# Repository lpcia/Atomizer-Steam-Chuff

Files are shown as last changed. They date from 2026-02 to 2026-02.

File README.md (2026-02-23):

# Atomizer-Steam-Chuff
Small circuit Using a 5V Humidifier/Atomizer Module to simulate Locomotive Steam Chuff using Track Power

# Steam Chuff Controller Build Guide  
   (Yes, it was created by AI and it kind of sucks, but it's pretty complete until I can edit it.)

## Complete 555-Based Ultrasonic Atomizer Controller for Model Railroads

---

## Table of Contents

1. [Project Overview](#project-overview)
2. [Critical Safety Warnings](#critical-safety-warnings)
3. [Components List](#components-list)
4. [Power Supply Setup](#power-supply-setup)
5. [555 Timer Circuit Build](#555-timer-circuit-build)
6. [MOSFET Power Stage](#mosfet-power-stage)
7. [Atomizer Connection](#atomizer-connection)
8. [Complete Wiring Summary](#complete-wiring-summary)
9. [Testing and Operation](#testing-and-operation)
10. [Troubleshooting](#troubleshooting)
11. [Maintenance Guidelines](#maintenance-guidelines)

---

## Project Overview

This steam chuff controller creates realistic steam locomotive effects using an ultrasonic atomizer synchronized to variable pulse timing. A 555 timer generates adjustable pulses that drive a MOSFET power stage, which switches the atomizer on and off to create "chuff" bursts of mist.

**Key Features:**
- Variable chuff rate control via potentiometer
- Adjustable pulse width for mist intensity
- Drives 5V, 300mA ultrasonic atomizer
- Operates from 18-24V DC/AC input
- Regulated 5V output via LM2596S buck converter

**Applications:**
- N-scale, HO-scale, and O-scale model steam locomotives
- Stationary industrial steam effects
- Model railway scenery effects

---

## Critical Safety Warnings

### ⚠️ ELECTRICAL SHOCK AND SHORT CIRCUIT DANGER

**NEVER operate atomizers with standing water near electrical components or power supplies.**

#### Specific Hazards:

1. **Water Conductivity:**
   - Standing water can create conductive paths between circuit traces
   - Mist/spray from atomizer can settle on PCBs and components
   - Water bridges can cause short circuits between +5V and ground
   - Can damage the LM2596S buck converter, 555 circuit, or MOSFET

2. **Shock Hazard:**
   - 18-24V input voltage can cause electrical shock through water
   - Even 5V circuits can cause component damage from water-induced shorts
   - Water + electricity = serious safety risk

3. **Component Damage:**
   - Corrosion of solder joints and copper traces
   - Electrolytic capacitor damage from moisture
   - MOSFET gate oxide damage from condensation

#### Safe Operating Practices:

✓ **Isolate the atomizer disc** - only the atomizer ceramic disc and its immediate holder should contact water

✓ **Waterproof enclosure** - house all electronics in a sealed, waterproof enclosure away from mist

✓ **Separate compartments** - physically separate the water reservoir from all circuit boards

✓ **Conformal coating** - consider coating PCBs with conformal coating for moisture protection

✓ **Drainage** - ensure any condensation can drain away from electronics

✓ **Regular inspection** - check for moisture accumulation in electronic compartments

✓ **Wire routing** - route wires so water cannot travel along them into electronics

#### For Model Railroad Installation:

- Mount the electronics ABOVE the water reservoir so gravity prevents water entry
- Use sealed cable glands where wires enter the electronics enclosure
- Install the atomizer disc in a separate, sealed water chamber
- Only the atomizer ceramic disc should be exposed to water
- Keep the atomizer PCB module dry and away from direct mist exposure

**DISCONNECT POWER IMMEDIATELY if you observe:**
- Water or condensation on circuit boards
- Unexpected behavior or intermittent operation
- Visible corrosion or discoloration on components
- Sparking, smoke, or unusual odors

---

### ⚠️ ATOMIZER OPERATION HAZARDS

**NEVER let ultrasonic atomizers run dry or operate in standing water that covers the atomizer disc.**

#### Atomizer-Specific Hazards:

1. **Dry Running Damage:**
   - Operating the atomizer WITHOUT water causes immediate overheating
   - The piezoelectric ceramic disc will crack or delaminate from the metal plate
   - Permanent atomizer failure within seconds
   - **ALWAYS ensure the disc is submerged before applying power**

2. **Excessive Water Depth:**
   - Water level should just cover the atomizer disc surface (typically 5-10mm above disc)
   - TOO MUCH water depth reduces mist output significantly
   - Can cause backpressure and reduce atomizer lifespan
   - Water should NOT cover the entire atomizer PCB module - only the ceramic disc

3. **Water Quality:**
   - Use distilled or deionized water only
   - Tap water minerals will cake on the disc and reduce performance
   - Mineral buildup requires cleaning with vinegar or citric acid
   - Dirty water shortens atomizer life dramatically

4. **Standing/Stagnant Water:**
   - Do not leave water standing in reservoir for extended periods
   - Bacteria and algae growth will clog the atomizer disc holes (740 tiny 5µm holes!)
   - Change water regularly, especially in warm environments
   - Clean reservoir between uses

#### Proper Water Level:

**Correct:** Water level 5-10mm (about ¼ inch) above the atomizer disc surface
- Disc is submerged but not deeply covered
- Maximum mist production
- Efficient operation

**Too Shallow:** Disc partially exposed
- Risk of dry-running damage
- Inconsistent mist output

**Too Deep:** Water more than 20mm above disc
- Reduced mist output
- Wasted power

---

### ⚠️ CRITICAL HEALTH HAZARD - STAGNANT WATER TOXICITY

**Stagnant water in atomizers can create TOXIC AIRBORNE BACTERIA including Legionella (Legionnaires' disease)**

#### Serious Health Risks:

1. **Legionella Bacteria:**
   - Thrives in stagnant, warm water (20°C-50°C / 68°F-122°F)
   - Atomizer disperses bacteria as fine aerosol particles (< 5µm)
   - **INHALING contaminated mist can cause severe pneumonia (Legionnaires' disease)**
   - Can be FATAL, especially for elderly, immunocompromised, or people with lung conditions
   - Symptoms: fever, cough, shortness of breath, muscle aches

2. **Other Waterborne Pathogens:**
   - Pseudomonas, E. coli, and other bacteria can colonize standing water
   - Mold spores and fungi can grow in reservoir
   - All become airborne when atomized
   - Can trigger asthma, allergic reactions, respiratory infections

3. **Biofilm Formation:**
   - Slimy bacterial layer forms on surfaces in 24-48 hours
   - Protects bacteria from casual cleaning
   - Continuously seeds water with pathogens
   - Very difficult to remove once established

#### MANDATORY Safety Protocols:

✓ **NEVER reuse water** - empty reservoir after EVERY use

✓ **Daily fresh water** - use only freshly filled distilled water

✓ **Empty when not in use** - store reservoir completely dry

✓ **Weekly disinfection** - clean with diluted bleach solution (1:10) or hydrogen peroxide, rinse thoroughly

✓ **Use distilled water only** - tap water contains nutrients that feed bacterial growth

✓ **Operate in ventilated area** - never in enclosed spaces without air exchange

✓ **Replace water after 4-6 hours** of operation, even if still in use

#### For Model Railroad Use:

- **DO NOT run continuously for hours unattended**
- Change water between operating sessions
- Dry out reservoir completely between uses
- Consider UV sterilization in reservoir if running extended periods
- Install in well-ventilated layout room
- Consider adding biocide (food-grade hydrogen peroxide) for longer sessions

#### Warning Signs of Contamination:

⚠️ Slimy feel on atomizer disc or reservoir walls

⚠️ Cloudy or discolored water

⚠️ Musty or unpleasant odor

⚠️ Visible algae or biofilm

**If any of these appear: STOP USE IMMEDIATELY, thoroughly disinfect all components, and replace water**

#### Who Is Most At Risk:

- People over 50 years old
- Smokers or former smokers
- People with chronic lung disease (COPD, emphysema)
- Immunocompromised individuals
- Anyone with weakened immune systems

**BOTTOM LINE: Treat atomizer water like a potential biohazard. Fresh water only. Empty after use. Clean regularly. Your lungs depend on it.**

---

## Components List

### 555 Timer Circuit:
- 1× NE555 timer IC (or TLC555 for CMOS version)
- 1× 8-pin DIP socket (recommended for easy replacement)
- 1× 47kΩ resistor, ¼W (yellow-violet-orange)
- 1× 100kΩ potentiometer, linear taper (chuff rate control)
- 1× 10µF electrolytic capacitor, 16V or higher (timing capacitor)
- 1× 1N4148 switching diode (asymmetric charge/discharge)
- 1× 980Ω resistor, ¼W (white-gray-brown) - can substitute 1kΩ
- 1× 10kΩ resistor, ¼W (brown-black-orange) - MOSFET gate pull-down

### Power Stage:
- 1× IRLZ44N N-channel MOSFET, TO-220 package (logic-level, 47A rated)
- 1× TO-220 heatsink (optional, not required for 300mA load)

### Power Supply:
- 18-24V AC or DC input source
- 1× Bridge rectifier, 1A+ rated (if using AC input)
- 1× LM2596S DC-DC buck converter module
- 2× 100µF electrolytic capacitors, 35V (input/output filtering, optional)

### Atomizer Load:
- 1× 5V USB humidifier atomization module
  - Specifications: 5V, 300mA, 2W, 110kHz, 16mm disc
  - PCB size: 35mm × 19mm
  - 740 holes, 5µm aperture

### Construction Materials:
- Perfboard or PCB (recommend 50mm × 70mm minimum)
- 22-24 AWG hookup wire (stranded preferred)
- Solder and soldering iron
- Wire strippers
- Multimeter
- Heat shrink tubing
- Cable ties
- Waterproof enclosure for electronics

---

## Power Supply Setup

### Step 1: Connect Bridge Rectifier (if using AC input)

**If using DC input (18-24V DC), skip to Step 2.**

1. Identify bridge rectifier terminals:
   - Two AC input terminals (marked ~ or AC)
   - (+) DC output terminal (marked + or positive)
   - (-) DC output terminal (marked - or negative/ground)

2. Connect input power:
   - 18-24V AC source → Bridge rectifier AC terminals (polarity doesn't matter)

3. Connect to buck converter:
   - Bridge rectifier (+) → LM2596S IN+ terminal
   - Bridge rectifier (-) → LM2596S IN- terminal

**If using DC input:**
- (+) 18-24V DC → LM2596S IN+
- (-) 18-24V DC → LM2596S IN-

### Step 2: Adjust LM2596S Buck Converter Output

1. **Before connecting any load**, apply input power to LM2596S

2. Connect multimeter in DC voltage mode:
   - Red probe → LM2596S OUT+ terminal
   - Black probe → LM2596S OUT- terminal

3. Locate small blue potentiometer on LM2596S module

4. Using small screwdriver, slowly turn potentiometer while monitoring voltage

5. Adjust until multimeter reads **exactly 5.0V DC**

6. Disconnect input power

### Step 3: Establish Power Rails

For the rest of this build, we'll refer to:
- **+5V rail** = LM2596S OUT+ terminal
- **Ground rail** = LM2596S OUT- terminal

**Power capacity:**
- Your LM2596S can provide up to 3A at 5V
- This circuit draws approximately 350-400mA total
- Plenty of headroom for stable operation

---

## 555 Timer Circuit Build

### Recommended Build Order:

Work from the IC outward, building power connections first, then timing components, then output stage.

### Pin Identification:

NE555 in 8-pin DIP package, notch at top:

```
        ┌─────┐
   GND  │1   8│  VCC
  TRIG  │2   7│  DISCH
   OUT  │3   6│  THRESH
 RESET  │4   5│  CTRL
        └─────┘
```

### Pin 1 (Ground):
- Connect directly to **ground rail**
- Use short, direct wire (keep ground paths short)

### Pin 8 (VCC):
- Connect directly to **+5V rail**
- Use short, direct wire

### Pin 4 (Reset):
- Connect to **+5V rail**
- This keeps the 555 enabled at all times
- Can share the same connection point as Pin 8

### Pin 5 (Control Voltage):
- Leave unconnected (floating)
- **Optional:** Add 0.01µF ceramic capacitor from Pin 5 to ground for noise immunity
- Not required for basic operation

### Pin 7 (Discharge):

This is the charging circuit connection point. Three things connect here:

1. **47kΩ resistor:**
   - One end to Pin 7
   - Other end to +5V rail

2. **Potentiometer End 1:**
   - Connect to Pin 7 (same point as 47kΩ resistor)

3. **1N4148 Diode Cathode:**
   - Cathode (end with black band) to Pin 7
   - Same connection point as above

**All three components share the Pin 7 connection node.**

### Pin 6 (Threshold) and Pin 2 (Trigger):

These pins are connected together and form the capacitor/timing node:

1. **Jumper wire between Pin 6 and Pin 2**
   - Short, direct connection

2. **10µF Capacitor positive (+) lead:**
   - Connect to Pin 6/Pin 2 junction
   - Observe polarity! Longer lead = positive
   - Negative lead goes to ground rail

3. **Potentiometer End 2:**
   - Connect to Pin 6/Pin 2 junction (same point as capacitor positive)

**All three items share the Pin 6/Pin 2 connection node.**

### Pin 3 (Output):

This drives the MOSFET gate through a current-limiting resistor:

1. **980Ω resistor:**
   - One end to Pin 3
   - Other end will connect to MOSFET gate (next section)

### Potentiometer Wiper:

The potentiometer has three terminals:
- End 1 → Pin 7 (already connected)
- End 2 → Pin 6/2 (already connected)
- Wiper (center terminal) → 1N4148 diode anode

**1N4148 Diode:**
- Anode (end WITHOUT black band) → Potentiometer wiper
- Cathode (end WITH black band) → Pin 7

### Circuit Topology Summary:

The 555 timer is configured as an astable oscillator with asymmetric duty cycle:

**Charging path:** +5V → 47kΩ → Pin 7 → Pot (End 1 to Wiper) → Diode → Pin 6/2 → Capacitor → Ground

**Discharging path:** Capacitor → Pin 6/2 → Pin 7 (internal discharge transistor) → Ground

The diode blocks the discharge path through the potentiometer, forcing discharge through Pin 7 only. This creates the asymmetric waveform needed for steam chuff effects.

---

## MOSFET Power Stage

The IRLZ44N MOSFET switches the atomizer on and off based on the 555 output pulses.

### IRLZ44N Pin Identification:

**Looking at the MOSFET from the front (with part number visible, pins pointing down):**

```
  ┌───────────┐
  │ IRLZ44N   │  ← Part number side (front)
  │           │
  └───────────┘
   │   │   │
   │   │   └── Source (S)
   │   └────── Drain (D)
   └────────── Gate (G)
  Left Middle Right
```

- **Left pin = Gate (G)**
- **Middle pin = Drain (D)**
- **Right pin = Source (S)**

### Gate Connection (Left Pin):

The gate requires two connections:

1. **980Ω resistor from 555 Pin 3:**
   - Connect the free end of the 980Ω resistor (already connected to 555 Pin 3) to MOSFET gate

2. **10kΩ pull-down resistor:**
   - One end to MOSFET gate (same point as 980Ω)
   - Other end to ground rail
   - This ensures the MOSFET stays OFF when 555 output is low

### Drain Connection (Middle Pin):

- Connect to **atomizer negative (-)** wire (black wire)
- This is the switched output that controls atomizer power

### Source Connection (Right Pin):

- Connect directly to **ground rail**
- Use short, direct connection
- This completes the switching path to ground

### Why IRLZ44N?

- **Logic-level gate:** Fully turns on with 5V gate voltage (555 output is ~3.6V when loaded, which is sufficient)
- **High current capacity:** 47A continuous rating (way more than needed for 300mA atomizer)
- **Low on-resistance:** Typically 0.022Ω when fully on, minimal voltage drop and heat
- **Avalanche rated:** Protects against inductive kick-back

**Heat sink not required** for this low-power application (2W load), but you can add one if desired.

---

## Atomizer Connection

### Atomizer Module Specifications:

Your 5V USB humidifier atomization module has two wires:
- **Red wire = Positive (+), 5V supply**
- **Black wire = Negative (-), ground return**

### Connections:

**Atomizer Positive (Red wire):**
- Connect to **+5V rail** (LM2596S OUT+)
- This provides constant 5V power to the atomizer

**Atomizer Negative (Black wire):**
- Connect to **IRLZ44N Drain** (middle pin)
- The MOSFET switches this connection to ground

### How It Works:

When 555 output (Pin 3) goes HIGH:
- MOSFET gate is pulled HIGH through 980Ω resistor
- MOSFET turns ON (conducts)
- Drain connects to Source (ground)
- Atomizer negative wire connects to ground through MOSFET
- Atomizer operates: 5V appears across atomizer (red to black)
- **Mist is produced**

When 555 output (Pin 3) goes LOW:
- MOSFET gate is pulled LOW by 10kΩ resistor
- MOSFET turns OFF (does not conduct)
- Drain is disconnected from ground
- No current flows through atomizer
- **No mist produced**

The 555 oscillator creates pulses that turn the MOSFET on and off, creating "chuff" bursts of mist synchronized to the adjustable timing.

### Wire Routing:

- Keep atomizer wires away from 555 timing components (minimize noise coupling)
- Use twisted pair if possible for atomizer wires
- Route through waterproof cable gland when passing through enclosure wall
- Ensure wires cannot carry water back into electronics enclosure

---

## Complete Wiring Summary

### Visual Reference:

```
INPUT POWER (18-24V AC/DC)
        ↓
   [Bridge Rectifier] (if AC)
        ↓
   [LM2596S Buck Converter] → Set to 5.0V output
        ↓
    +5V  GND
     │    │
     │    ├─────────────────────────────┐
     │    │                             │
     ├────┤                             │
     │    │                             │
┌────┴────┴────┐                        │
│   NE555      │                        │
│              │                        │
│ 8(VCC)  1(GND)                        │
│ 4(RST)  5(CV)-open                    │
│              │                        │
│ 7(DISCH)───┬─┤                        │
│            │ │                        │
│   47kΩ to +5V│                        │
│   Pot End 1 ─┤                        │
│   Diode Cathode                       │
│              │                        │
│ 6(THR)───┬───┤                        │
│ 2(TRIG)──┤   │                        │
│          │   │                        │
│   Pot End 2 ─┤                        │
│   10µF Cap(+)│                        │
│      Cap(-) to GND                    │
│              │                        │
│ Pot Wiper ───┤                        │
│   Diode Anode│                        │
│              │                        │
│ 3(OUT)───980Ω───┐                     │
│                 │                     │
└─────────────────┼─────────────────────┘
                  │
            ┌─────┴─────┐
            │ IRLZ44N   │
            │ Gate  ←───┤  (+ 10kΩ to GND)
            │           │
            │ Drain ────┼──→ Atomizer (-)
            │           │
            │ Source ───┼──→ GND
            └───────────┘
                        
    Atomizer (+) → +5V rail
    Atomizer (-) → MOSFET Drain
```

### Connection Checklist:

**Power Rails:**
- [ ] LM2596S adjusted to exactly 5.0V output
- [ ] +5V rail established from LM2596S OUT+
- [ ] Ground rail established from LM2596S OUT-

**555 Timer:**
- [ ] Pin 1 (GND) → Ground rail
- [ ] Pin 8 (VCC) → +5V rail
- [ ] Pin 4 (RST) → +5V rail
- [ ] Pin 5 (CTRL) → Unconnected (or 0.01µF cap to ground)
- [ ] Pin 2 and Pin 6 jumpered together
- [ ] Pin 3 (OUT) → 980Ω resistor → MOSFET gate

**Timing Components:**
- [ ] 47kΩ resistor: one end to +5V, other end to Pin 7
- [ ] 10µF capacitor: (+) to Pin 6/2 junction, (-) to ground
- [ ] Potentiometer End 1 → Pin 7
- [ ] Potentiometer End 2 → Pin 6/2 junction
- [ ] Potentiometer Wiper → 1N4148 anode (no band)
- [ ] 1N4148 cathode (black band) → Pin 7

**MOSFET Stage:**
- [ ] 980Ω from 555 Pin 3 → IRLZ44N Gate (left pin)
- [ ] 10kΩ resistor: Gate to Ground (pull-down)
- [ ] IRLZ44N Drain (middle pin) → Atomizer (-) black wire
- [ ] IRLZ44N Source (right pin) → Ground rail

**Atomizer:**
- [ ] Atomizer (+) red wire → +5V rail
- [ ] Atomizer (-) black wire → MOSFET Drain

**Double-Check:**
- [ ] No short circuits between +5V and Ground
- [ ] Electrolytic capacitor polarity correct
- [ ] Diode polarity correct (cathode/black band to Pin 7)
- [ ] MOSFET orientation correct
- [ ] All solder joints clean and solid
- [ ] No loose wire strands that could cause shorts

---

## Testing and Operation

### Test Procedure:

**Always test in stages to isolate any problems.**

### Stage 1: Power Supply Test (No Load)

1. **Disconnect atomizer** from circuit

2. Apply input power (18-24V)

3. **Measure voltages:**
   - LM2596S output: Should read **5.0V DC** (±0.1V)
   - 555 Pin 8: Should read **5.0V DC**
   - 555 Pin 1: Should read **0.0V** (ground reference)

4. If voltages are incorrect:
   - Check LM2596S input voltage (should be 18-24V after bridge rectifier)
   - Re-adjust LM2596S potentiometer
   - Check for short circuits

5. If all voltages correct, proceed to Stage 2

### Stage 2: 555 Oscillator Test

**With power still applied (atomizer still disconnected):**

1. **Set multimeter to DC voltage mode**

2. **Measure 555 Pin 3 (output):**
   - Should be toggling between approximately **0V and 3.6-4.5V**
   - If using analog meter, you'll see needle bounce
   - If using digital meter, reading will jump around

3. **Adjust potentiometer through its full range:**
   - Frequency should change (visible as changing rate of voltage toggling)
   - At one extreme: slower toggling
   - At other extreme: faster toggling

4. **If Pin 3 is stuck HIGH or LOW:**
   - Check Pin 2 and Pin 6 are connected together
   - Verify 10µF capacitor polarity (+ to Pin 6/2, - to ground)
   - Check diode orientation (cathode/band to Pin 7)
   - Verify potentiometer End 2 goes to Pin 6/2 junction
   - Check Pin 4 is connected to +5V (not floating)

5. **If Pin 3 oscillates correctly, proceed to Stage 3**

### Stage 3: Oscilloscope Verification (Optional but Recommended)

**If you have an oscilloscope available:**

1. **Connect oscilloscope:**
   - Channel 1 probe → 555 Pin 3 (output)
   - Channel 2 probe → 555 Pin 6 (capacitor voltage)
   - Ground clips → Circuit ground

2. **Oscilloscope settings:**
   - Timebase: 10-20 ms/div
   - CH1 voltage: 2V/div
   - CH2 voltage: 2V/div
   - Trigger: CH1, rising edge, ~2.5V level

3. **Expected waveforms:**
   - **CH1 (Pin 3):** Square wave, mostly HIGH with brief LOW pulses
   - **CH2 (Pin 6):** Sawtooth/ramp waveform, charging up then dropping sharply

4. **Adjust potentiometer and observe:**
   - Slope of CH2 sawtooth should change (steeper = faster charge)
   - Width of LOW pulses on CH1 should change correspondingly
   - Frequency should change

5. **Typical frequency range:** 20-200 Hz depending on pot position

### Stage 4: MOSFET Switching Test

**Still without atomizer connected:**

1. **Measure MOSFET Drain voltage** (middle pin, where atomizer will connect)

2. Should be switching between:
   - **~0V** when MOSFET is ON (555 Pin 3 HIGH)
   - **~5V** when MOSFET is OFF (555 Pin 3 LOW)

3. **Digital multimeter will show average voltage:**
   - Typical reading: 0.5V to 2V (depends on duty cycle)
   - This is normal - meter is averaging the switching

4. **Adjust potentiometer:**
   - Drain average voltage should change
   - At one extreme: ~0.5-1V (MOSFET ON most of time)
   - At other extreme: ~0V (MOSFET ON nearly all the time)

5. **If Drain stays at 5V (MOSFET never turns on):**
   - Check 980Ω resistor connection from 555 Pin 3 to MOSFET gate
   - Verify MOSFET is oriented correctly
   - Check 10kΩ pull-down is not shorting gate to ground

6. **If Drain stays at 0V (MOSFET always on):**
   - Check for short between MOSFET gate and source
   - Verify 555 Pin 3 is oscillating (go back to Stage 2)

### Stage 5: Full System Test with Atomizer

**CRITICAL: Before connecting atomizer, ensure water reservoir is properly set up per safety warnings!**

1. **Prepare water reservoir:**
   - Use only distilled or deionized water
   - Fill to proper level (5-10mm above atomizer disc)
   - Verify atomizer disc is fully submerged
   - Ensure electronics are isolated from water

2. **Connect atomizer:**
   - Red wire (+) → +5V rail
   - Black wire (-) → MOSFET Drain

3. **Apply power**

4. **Expected behavior:**
   - Atomizer should produce pulsing bursts of mist
   - "Chuff" effect: short bursts of mist synchronized to 555 timing
   - No continuous mist (if continuous, see troubleshooting)

5. **Adjust potentiometer:**
   - Should change the rate of chuff bursts
   - At one extreme: slower chuffs (longer period between bursts)
   - At other extreme: faster chuffs (shorter period between bursts)

6. **Verify operation:**
   - Mist production should be consistent
   - No overheating of components
   - MOSFET should remain cool (slight warmth is normal)
   - No unusual smells or sounds

### Stage 6: Fine Tuning

1. **Adjust potentiometer for desired chuff rate:**
   - Typical model railroad: 2-4 chuffs per second for slow speed
   - Faster speeds: 4-8 chuffs per second

2. **Observe mist characteristics:**
   - Each chuff should be a distinct burst
   - Mist volume should be appropriate for scale
   - Adjust water level if needed for mist density

3. **Mark potentiometer positions:**
   - Use permanent marker to note positions for different "locomotive speeds"
   - This allows quick adjustment during operation

### Successful Operation Indicators:

✓ 5.0V at +5V rail
✓ 555 Pin 3 oscillating between 0V and ~3.6-4.5V
✓ MOSFET Drain switching between ~0V and ~5V
✓ Potentiometer changes frequency/duty cycle
✓ Atomizer produces pulsing mist bursts
✓ No overheating, no unusual odors
✓ No water in electronics enclosure

**If all tests pass, your steam chuff controller is complete and operational!**

---

## Troubleshooting

### Problem: No power at +5V rail

**Symptoms:** LM2596S output reads 0V or very low voltage

**Possible Causes:**
- No input voltage to LM2596S
- Bridge rectifier connected backwards (if using AC input)
- LM2596S damaged or defective
- Short circuit on output

**Solutions:**
1. Measure input voltage at LM2596S input terminals (should be 18-24V DC)
2. If using AC input, verify bridge rectifier polarity
3. Disconnect all loads from LM2596S output and re-measure (if voltage appears, you have a short circuit in your load)
4. Try adjusting LM2596S potentiometer through full range
5. If still no output, LM2596S may be damaged - replace module

### Problem: 555 Pin 3 stuck HIGH (always ~4-5V)

**Symptoms:** No oscillation, output doesn't pulse, no mist

**Possible Causes:**
- Pin 2 (Trigger) not connected to Pin 6 (Threshold)
- Capacitor not connected or defective
- Capacitor polarity reversed
- Pin 4 (Reset) floating or grounded

**Solutions:**
1. Verify jumper wire between Pin 2 and Pin 6
2. Check 10µF capacitor connections: (+) to Pin 6/2, (-) to ground
3. Verify capacitor polarity (long lead = positive)
4. Confirm Pin 4 is connected to +5V rail
5. Try replacing capacitor (may be defective)

### Problem: 555 Pin 3 stuck LOW (always ~0V)

**Symptoms:** No oscillation, MOSFET always ON, continuous mist

**Possible Causes:**
- Pin 7 (Discharge) shorted to ground
- Diode installed backwards
- Potentiometer End 1 not connected to Pin 7

**Solutions:**
1. Check diode orientation: cathode (black band) should be at Pin 7
2. Verify potentiometer End 1 connects to Pin 7
3. Check for accidental solder bridges shorting Pin 7 to ground
4. Verify 47kΩ resistor is connected between +5V and Pin 7

### Problem: 555 oscillates but frequency doesn't change with pot

**Symptoms:** Mist pulses but pot adjustment has no effect

**Possible Causes:**
- Pot wiper not connected to diode anode
- Pot End 2 not connected to Pin 6/2
- Defective potentiometer
- Diode installed backwards

**Solutions:**
1. Verify pot wiper connects to diode anode (end WITHOUT black band)
2. Verify pot End 2 connects to Pin 6/2 junction (with capacitor positive)
3. Measure resistance across pot while rotating - should change smoothly from ~0Ω to 100kΩ
4. Check diode orientation: anode (no band) to pot wiper, cathode (band) to Pin 7
5. Replace potentiometer if defective

### Problem: MOSFET always ON (Drain always ~0V)

**Symptoms:** Continuous mist, no pulsing

**Possible Causes:**
- MOSFET gate shorted to +5V
- 10kΩ pull-down resistor missing or disconnected
- 555 output stuck HIGH (see above)
- Wrong MOSFET type (not logic-level)

**Solutions:**
1. Verify 555 Pin 3 is oscillating (see Stage 2 testing)
2. Check 10kΩ pull-down resistor from gate to ground is installed
3. Measure gate voltage - should pulse between 0V and 3-4V
4. Verify MOSFET part number is IRLZ44N (logic-level)
5. Check for solder bridges between gate and drain pins

### Problem: MOSFET never turns ON (Drain always ~5V)

**Symptoms:** No mist, atomizer never activates

**Possible Causes:**
- 980Ω resistor not connected from 555 Pin 3 to gate
- MOSFET installed backwards
- Gate shorted to source (always 0V)
- Defective MOSFET

**Solutions:**
1. Verify 980Ω resistor connects 555 Pin 3 to MOSFET gate
2. Check MOSFET orientation: Gate (left), Drain (middle), Source (right) when viewing from front
3. Measure voltage at MOSFET gate - should pulse with 555 output
4. Measure continuity between gate and source - should be open circuit (infinite resistance)
5. Replace MOSFET if defective

### Problem: Weak or no mist production

**Symptoms:** Atomizer receives power but produces little or no mist

**Possible Causes:**
- Water level incorrect
- Tap water mineral buildup on disc
- Atomizer disc damaged or worn
- Insufficient voltage (less than 4.5V)
- Atomizer running dry previously (thermal damage)

**Solutions:**
1. Check water level: should be 5-10mm above disc surface
2. Clean atomizer disc with cotton swab and distilled water
3. If mineral buildup, soak in white vinegar for 10 minutes, rinse thoroughly
4. Measure voltage across atomizer during operation (should be 5.0V when pulsing ON)
5. Test atomizer directly with 5V DC to verify it's functional
6. Replace atomizer if damaged

### Problem: Erratic or inconsistent operation

**Symptoms:** Intermittent operation, random pulsing, unstable frequency

**Possible Causes:**
- Poor solder joints (cold solder joints)
- Loose connections
- Breadboard contact issues (if not soldered)
- Electrolytic capacitor drying out or failing
- Noise coupling from atomizer to 555 circuit

**Solutions:**
1. Reflow all solder joints, especially on 555 pins
2. Check for loose wires or connectors
3. If using breadboard, transfer to permanent soldered construction
4. Replace electrolytic capacitor
5. Add 0.01µF ceramic capacitor from 555 Pin 5 to ground (noise filtering)
6. Route atomizer wires away from 555 timing components
7. Add 100µF capacitor directly across +5V and ground near 555 IC

### Problem: MOSFET gets hot

**Symptoms:** MOSFET is warm or hot to touch during operation

**Possible Causes:**
- MOSFET not fully turning ON (operating in linear region)
- Gate voltage insufficient
- Wrong MOSFET type (not logic-level)
- Excessive current draw from atomizer

**Solutions:**
1. Verify MOSFET is IRLZ44N (logic-level type)
2. Measure gate voltage - should be 3-4V when ON
3. Measure atomizer current (should be ~300mA) - if much higher, atomizer may be shorted
4. Add heatsink to MOSFET if mild warmth continues
5. Replace MOSFET if very hot or if wrong part was used

### Problem: Rapid pulsing noise from atomizer

**Symptoms:** High-pitched buzzing or squealing from atomizer

**Possible Causes:**
- Normal ultrasonic operation (110kHz) - this is expected
- If exceptionally loud: check for mechanical resonance

**Solutions:**
1. Some audible noise at 110kHz is normal for ultrasonic atomizers
2. Ensure atomizer is properly mounted and not vibrating against other surfaces
3. Add rubber isolation if excessive mechanical noise
4. Verify water level is correct (too shallow can increase noise)

### Problem: Water in electronics enclosure

**Symptoms:** Moisture, condensation, or water on circuit board

**IMMEDIATE ACTION:**
1. **DISCONNECT POWER IMMEDIATELY**
2. Do not reconnect power until completely dry

**Remediation:**
1. Disassemble and dry all components thoroughly
2. Use isopropyl alcohol (90%+ purity) to clean water residue from PCB
3. Allow 24-48 hours drying time in warm, dry location
4. Inspect for corrosion on solder joints and component leads
5. Check all electrolytic capacitors (may be damaged by moisture)
6. Re-evaluate enclosure design - improve water isolation
7. Add conformal coating to PCB for moisture protection
8. Test thoroughly before returning to service

---

## Maintenance Guidelines

### Daily (Each Operating Session):

**Before Operation:**
- [ ] Empty old water from reservoir
- [ ] Fill with fresh distilled or deionized water
- [ ] Verify water level 5-10mm above atomizer disc
- [ ] Check for water accumulation in electronics enclosure
- [ ] Visual inspection of all connections

**After Operation:**
- [ ] Empty water reservoir completely
- [ ] Wipe atomizer disc with soft cloth
- [ ] Allow reservoir to dry with lid open
- [ ] Check for any signs of moisture in electronics

### Weekly:

- [ ] Clean atomizer disc with cotton swab and distilled water
- [ ] Inspect atomizer for mineral buildup (white crusty deposits)
- [ ] Check all wire connections for tightness
- [ ] Verify potentiometer operates smoothly through full range
- [ ] Test system operation through full pot adjustment range

### Monthly:

- [ ] Descale atomizer disc if using tap water:
  - Soak in white vinegar or citric acid solution for 10 minutes
  - Gently scrub with soft toothbrush
  - Rinse thoroughly with distilled water
  - Dry completely before use

- [ ] Disinfect water reservoir:
  - Mix 1 part household bleach with 10 parts water
  - Fill reservoir with solution
  - Let sit for 10 minutes
  - Drain completely
  - Rinse thoroughly 3-4 times with distilled water
  - Dry completely

- [ ] Inspect electronics enclosure for:
  - Moisture or condensation
  - Corrosion on solder joints
  - Discoloration of components
  - Loose connections

- [ ] Test all voltages with multimeter:
  - LM2596S output: 5.0V ±0.1V
  - 555 Pin 8: 5.0V
  - 555 Pin 3: Oscillating
  - MOSFET Drain: Switching

### Every 3-6 Months:

- [ ] Replace atomizer disc if:
  - Mist output has decreased significantly
  - Disc shows cracks or delamination
  - Heavy mineral buildup cannot be cleaned
  - Irregular mist pattern

- [ ] Inspect and clean potentiometer:
  - Spray with electrical contact cleaner
  - Rotate through full range several times
  - Check for scratchy or dead spots

- [ ] Check electrolytic capacitor:
  - Look for bulging or leaking
  - Test capacitance if meter available
  - Replace if more than 2-3 years old

### Annually:

- [ ] Complete system inspection and testing
- [ ] Replace electrolytic capacitor (preventive maintenance)
- [ ] Clean and re-solder any oxidized connections
- [ ] Test all components individually
- [ ] Update documentation with any modifications

### Signs Requiring Immediate Attention:

⚠️ **Visible water in electronics enclosure** - Shut down immediately, dry completely

⚠️ **Burning smell or smoke** - Disconnect power, identify failed component

⚠️ **Erratic operation** - Check for loose connections, failing components

⚠️ **No mist with full voltage** - Atomizer disc likely failed, replace

⚠️ **Overheating components** - MOSFET or LM2596S may be failing

⚠️ **Slimy or foul-smelling water** - Bacterial contamination, disinfect immediately

⚠️ **Corrosion on circuit board** - Water ingress, investigate and repair

---

## Conclusion

This steam chuff controller provides realistic pulsing mist effects for model railroad steam locomotives using a simple, reliable 555-based design. By following proper construction techniques and adhering to safety guidelines - especially regarding water isolation and bacterial contamination - you'll have a durable, effective system for bringing your steam locomotives to life.

**Key Takeaways:**

- **Safety first:** Isolate water from electronics, use fresh distilled water only
- **Test in stages:** Build confidence that each section works before moving forward
- **Maintenance matters:** Regular cleaning and fresh water prevent problems
- **Adjust to taste:** The potentiometer gives you full control over chuff rate and character

Enjoy your enhanced model railroad experience with realistic steam effects!

---

## Revision History

**Version 1.0** - February 2026
- Initial comprehensive build guide
- Complete safety warnings for electrical, atomizer, and health hazards
- Full troubleshooting section
- Maintenance guidelines

---

## Additional Resources

**Suggested Reading:**
- NE555 Timer IC Datasheet (Texas Instruments)
- IRLZ44N MOSFET Datasheet (Infineon/International Rectifier)
- LM2596 Buck Converter Application Notes

**Model Railroad Forums:**
- Search for "steam smoke unit" modifications
- Discussion of various mist generator technologies
- Integration with DCC sound decoders

**Safety Information:**
- CDC Guidelines on Legionella Prevention
- Humidifier Maintenance Best Practices

---

**Document prepared by: Paul**
**For: N-Scale Naval Logistics Support Center Lindakonetta Layout**
**Date: February 2026**

---

*This document is provided for educational and hobbyist purposes. Always follow electrical safety practices and local codes. The author assumes no liability for construction errors, component failures, or injuries resulting from use of this information.*

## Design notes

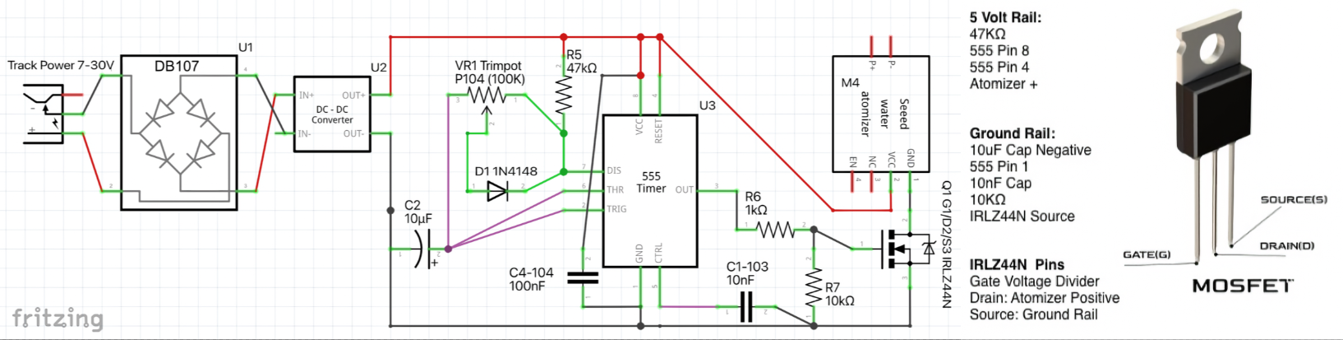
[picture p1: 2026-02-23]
Updated Steam Chuff Schematic.png

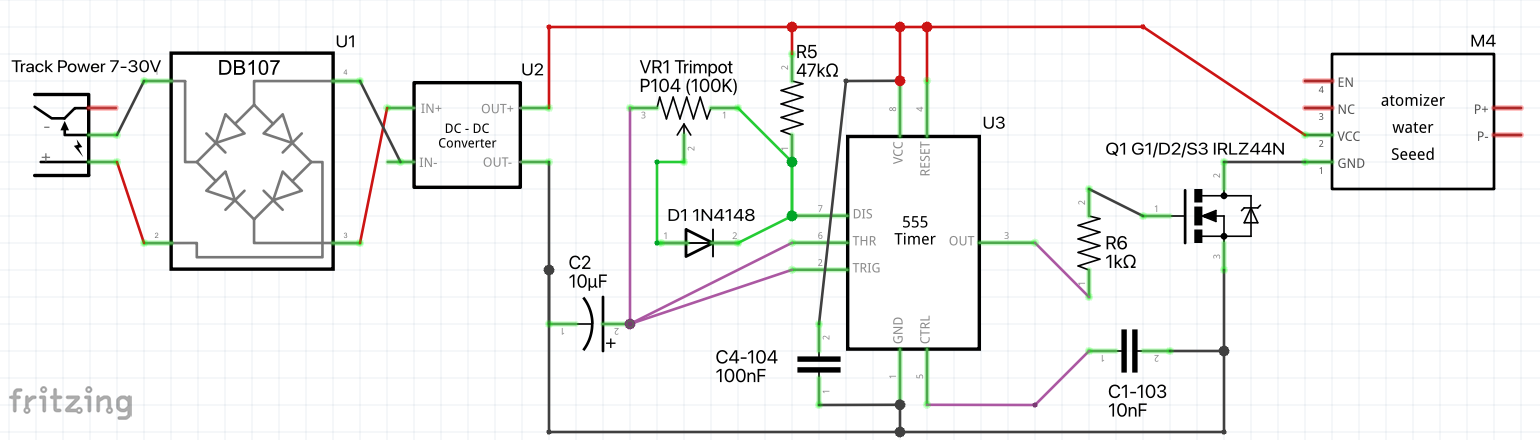
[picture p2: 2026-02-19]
Steam Chuff.png

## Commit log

2026-02-19 Add png schematic
2026-02-23 Add files via upload
    This replace Version 1 which is incorrect
    [Atomizer Chuff 555 v2.fzz]
